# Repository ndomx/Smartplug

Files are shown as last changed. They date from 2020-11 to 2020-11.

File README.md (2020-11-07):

# Smartplug
WiFi controller for home automation

## Description
A smartplug is a device with which you can control the conection of an appliance remotely. As of version 2, I'm using an ESP8266 micro-controller, and controlling it using MQTT.

The schematics are publicly available in this repository, and the fabrication files are available in the releases page. All the required codes are also publicly available here, though you'll have to setup your Arduino IDE to program the MCU. Refer to the [libraries guide](./LIBRARIES_GUIDE.md) to learn how to do it.

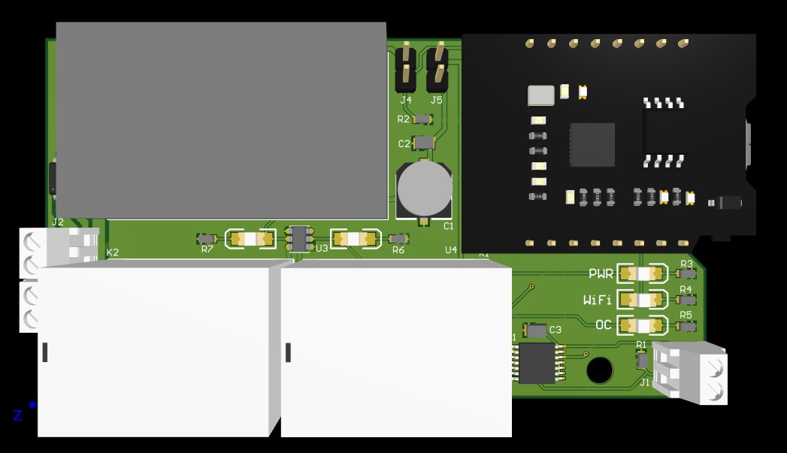
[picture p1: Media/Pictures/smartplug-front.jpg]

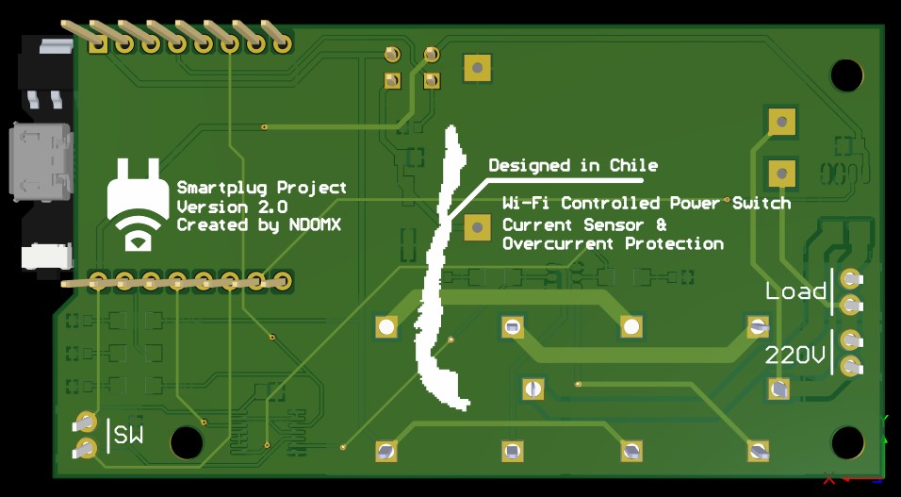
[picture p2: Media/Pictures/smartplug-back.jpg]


## Functionality
### Basics
The basic operation of the smartplug is fairly simple. It's a commutator circuit just like those lights, found commonly in stairs, that can be controlled by two switches. The circuit goes as follows:
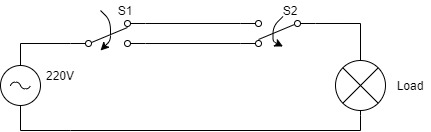
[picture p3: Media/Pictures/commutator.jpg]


Current can flow through the load (a light bulb) when bith switches are in the same state. The smartplug works the same way, but instead of having two switches, it has two relays that are controlled by the MCU.
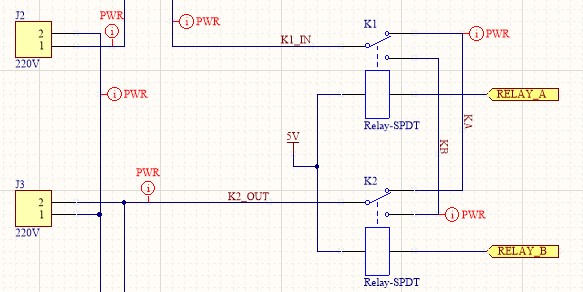
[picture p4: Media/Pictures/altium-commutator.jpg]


The MCU controls both signals, **RELAY_A** and **RELAY_B** that toggle each switch. One control signal is controlled remotely (via MQTT) while the other is controlled by an external switch.

The smartplug has two modes of operation:
1. Take absolute control of the load remotely, i.e. connect/disconnect the load remotely regardless of the external switch input
2. Use the smartplug as a traditional commutator circuit, i.e. the load will toggle every time each control signal is toggled, wether its via MQTT or physical input

> I noticed only one relay is necessary to achieve the same behaviour. So V3 will drop one relay and handle all the logic by software.

The mode of operation is controlled by the header J4.
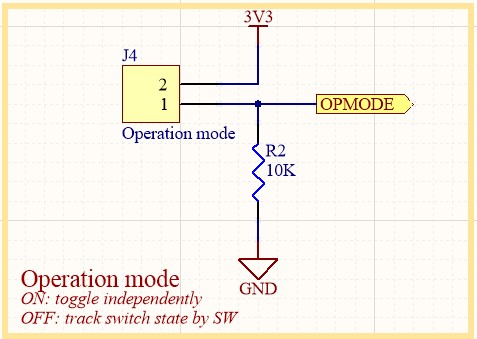
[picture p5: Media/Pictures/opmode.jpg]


### Power
The PCB traces were calculated for 5A max. In countries with 220V/50Hz supply, this can power 1kW loads. In countries with 110V/60Hz, the max output power is limited to 0.5kW.

On the other hand, all the electronics can be powered by the AC/DC module **X1**, or by external 5V connected to the USB connector, as shown in the image below.
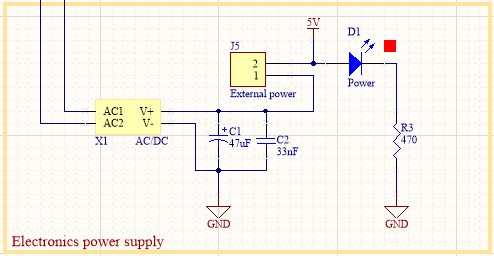
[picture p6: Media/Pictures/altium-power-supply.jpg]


Connect the jumper **J5** to enable power input from the AC/DC module, or leave disconnected and power via USB cable.
> Powering the device via USB cable is meant for uploading the firmware to the MCU. For other purposes, the use of the AC/DC module is recommended

### Current sensing
The smartplug is equipped with an ACS712 current sensor. The current is measured by the MCU ADC and uploaded to the server.

Additionally, if and overcurrent is detected, the OC flag will be activated (~OC as it is active low) and the output will be disabled.

The SN74LV (**U1**) is a quad NAND gate that implements the logic circuit that ensures the load remains unconnected while the OC flag is active.
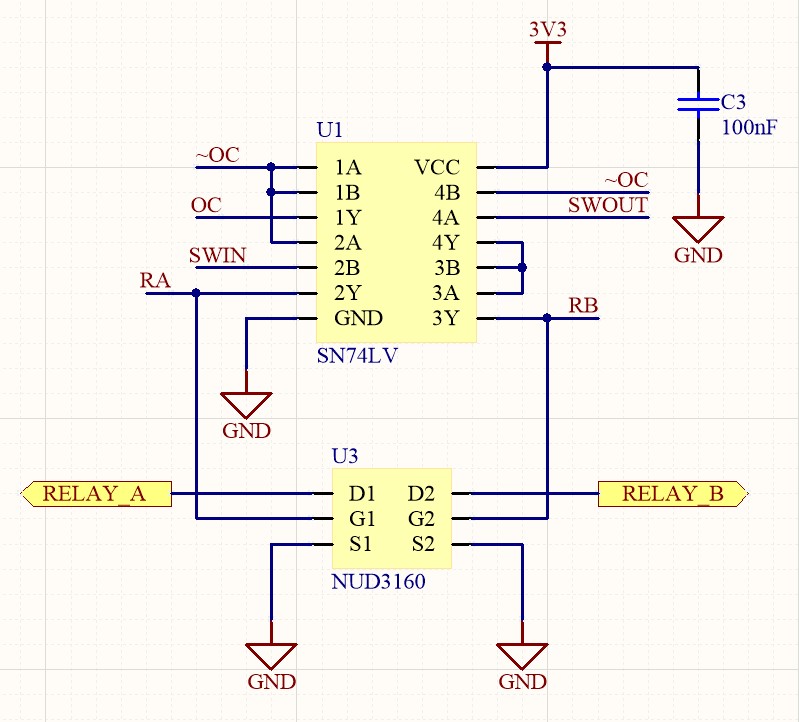
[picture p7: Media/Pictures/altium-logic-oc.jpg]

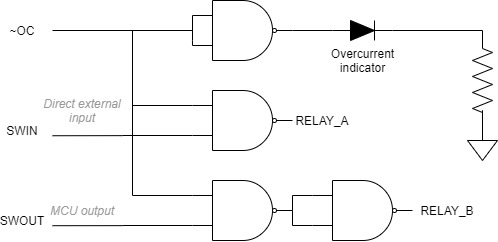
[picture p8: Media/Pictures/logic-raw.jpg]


When ~OC goes low, the outputs **RELAY_A** and **RELAY_B** will go HIGH/LOW repectively, thus, shutting down the load.

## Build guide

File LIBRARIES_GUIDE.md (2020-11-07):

# LIBRARIES GUIDE

## 1. ESP8266 Arduino library
1. Open the Arduino IDE
2. Go to _File_ > _Preferences_ and complete the field _Additional Boards Manager URLs_ with the following link ``http://arduino.esp8266.com/stable/package_esp8266com_index.json``
3. Go to _Tools_ > _Board_ > _Boards Manager..._
4. Search for ``esp8266`` and install the library **esp8266** by **ESP8266 Community**.
   
## 2. PubSubClient Arduino library
1. Open the Arduino IDE.
2. Go to _Sketch_ > _Include Library_ > _Manage Libraries..._
3. Search for ``PubSubClient`` and install the library **PubSubClient** by **Nick O'Leary**

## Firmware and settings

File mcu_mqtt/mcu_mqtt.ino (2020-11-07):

/*
 * Smartplug controller code for ESP8266.
 * Author: ndomx (https://github.com/ndomx)
 * 
 * This code uses the PubSubClient library and
 * is based on the example code provided the author.
 * Original code available on:
 * https://github.com/knolleary/pubsubclient/blob/master/examples/mqtt_esp8266/mqtt_esp8266.ino
 */

#include <Ticker.h>
#include <ESP8266WiFi.h>
#include <PubSubClient.h>

#include "private_data.h"
#include "esp8266_header.h"

String clientId = "ESP8266-sp1"; // Be sure to change it for each device

WiFiClient espClient;
PubSubClient client(espClient);

char pub_msg[PUB_MSG_LENGTH];

Ticker rms_calculation;
float amps_array[AMPS_ARRAY_LENGTH];
int amps_index;

float amps_rms;

long last_measurement;
bool is_resting;

void setup()
{
    pinMode(SWOUT, OUTPUT);
    pinMode(SWIN, INPUT);
    pinMode(OC, OUTPUT);
    pinMode(LED_WIFI, OUTPUT);
    pinMode(ADC_PIN, INPUT);

    // Ensure the OC flag starts deactivated
    digitalWrite(OC, HIGH);

    Serial.begin(115200);
    setup_wifi();
    setup_mqtt();

    rms_calculation.attach_ms(TICKER_INTERVAL_MS, measure_amps);
}

void loop()
{
    if (!client.connected())
    {
        reconnect();
    }
    client.loop();

    if (is_resting)
    {
        long now = millis();
        if (now - last_measurement > TICKER_REST_MS)
        {
            is_resting = false;
            rms_calculation.attach_ms(TICKER_INTERVAL_MS, measure_amps);
        }
    }
}

void setup_wifi()
{
    delay(10);
    
    Serial.println();
    Serial.print("Connecting to ");
    Serial.println(ssid);

    WiFi.begin(ssid, password);

    bool led_state = LOW;

    while (WiFi.status() != WL_CONNECTED)
    {
        delay(500);
        Serial.print(".");

        digitalWrite(LED_WIFI, led_state);
        led_state ^= HIGH;
    }

    Serial.println("");
    Serial.println("WiFi connected");
    Serial.println("IP address: ");
    Serial.println(WiFi.localIP());

    digitalWrite(LED_WIFI, LOW);
}

void setup_mqtt()
{
    client.setServer(mqtt_server, 1883);
    client.setCallback(on_message);

    client.subscribe(topic_power);
}

void on_message(char *topic, byte *payload, unsigned int length)
{
    digitalWrite(LED_WIFI, HIGH);

    Serial.print(topic);
    Serial.print(" | ");
    for (int i = 0; i < length; i++)
    {
        Serial.print((char)payload[i]);
    }
    Serial.println();
    
    toggle_plug(payload[0] == '1');

    digitalWrite(LED_WIFI, LOW);
}

void reconnect()
{
    digitalWrite(LED_WIFI, HIGH);
    while (!client.connected())
    {
        Serial.print("Attempting MQTT connection...");
        
        if (client.connect(clientId.c_str()))
        {
            Serial.println("connected");
            client.subscribe(topic_power);
        }
        else
        {
            Serial.print("failed, rc=");
            Serial.print(client.state());
            Serial.println(" try again in 5 seconds");
            delay(5000);
        }
    }
}

void publish(void)
{
    Serial.print("Publish: [");
    Serial.print(topic_amps);
    Serial.print("] amps_rms = ");
    Serial.println(amps_rms);
    
    snprintf(pub_msg, PUB_MSG_LENGTH, "amps_rms: %f", amps_rms);
    client.publish(topic_amps, pub_msg);
}

void measure_amps()
{
    // The current sample has an offset of Vdd/2,
    // so its necessary to substract 1024/2 from the
    // sampled value
    float amps = (analogRead(ADC_PIN) - 512) * MAX_AMPS / 512;

    amps_array[amps_index++] = amps * amps;
    if (amps_index >= AMPS_ARRAY_LENGTH)
    {
        amps_index = 0;
        on_measurement_ready();
    }
}

void on_measurement_ready()
{
    rms_calculation.detach();

    calculate_amps_rms();
    publish();

    last_measurement = millis();
    is_resting = true;
}

void calculate_amps_rms()
{
    float sum;
    for (int idx = 0; idx < AMPS_ARRAY_LENGTH; idx++)
    {
        sum += amps_array[idx];
    }
    
    amps_rms = sum / AMPS_ARRAY_LENGTH;
    /*
     * Technically, amps_rms would be equal to the sqrt of
     * the actual quantity, but its best not to calculate
     * sqrts in the mcu, but to calculate them server side
     */

    if (amps_rms > OVERCURRENT_TH * OVERCURRENT_TH)
    {
        // Theres no software way of clearing the OC flag
        // To turn it off, the MCU must be resetted
        digitalWrite(OC, LOW);
    }
}

void toggle_plug(bool next_state)
{
    bool opmode = digitalRead(OPMODE);
    if (opmode)
    {
        bool swin = digitalRead(SWIN);
        digitalWrite(SWOUT, swin);
    }
    else
    {
        digitalWrite(SWOUT, next_state);
    }
}

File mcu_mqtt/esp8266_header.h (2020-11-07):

/*
 * Header file for functions:
 * This file is read before the main code by the compiler, and so,
 * it allow us to make use of this functions before declaring them
 * in the main code.
 * 
 * The use of this kind of files is absolutely optional for small
 * codes/projects like this one, but I find it a good practice to
 * use them anyway.
 */

#ifndef ESP8266_HEADER_H
#define ESP8266_HEADER_H

#include <Arduino.h>

#define SWOUT D6
#define SWIN D0
#define OPMODE D3
#define OC D1
#define LED_WIFI D8
#define ADC_PIN A0

#define PUB_MSG_LENGTH 20

#define AMPS_ARRAY_LENGTH 40
#define TICKER_INTERVAL_MS 2

#define TICKER_REST_MS 1000

#define MAX_AMPS 30.0 // Max current supported by sensor
#define OVERCURRENT_TH 5 // OC threshold

void setup_wifi(void);

void setup_mqtt(void);
void on_message(char *topic, byte *payload, unsigned int length);
void reconnect(void);
void publish(void);

void measure_amps(void);
void calculate_amps_rms(void);
void on_measurement_ready(void);

void toggle_plug(bool next_state);

#endif // ESP8266_HEADER_H

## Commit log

2018-10-07 Update file
    Updated .gitignore to ommit Eagle PCB and editor autogenerated files
2018-10-07 Add files
    Eagle PCB design for Smartplug
    [smart-plug.brd, smart-plug.sch]
2018-10-07 Add files
    Nodejs REST API to communicate with end devices
2018-10-07 Update files
    Added LED indicators
    [smart-plug.brd, smart-plug.sch]
2018-12-20 Update files
    Improved led debugging
2018-12-20 Update files
    Added on board LEDs, updated design
    [smart-plug.brd, smart-plug.sch]
2018-12-20 Update mcu_mqtt.ino
    Changed RED LED pin
2018-12-21 Update mcu_mqtt.ino
    Set LED pins to output
2019-01-12 Update files
    Removed fuse and made PCB smaller
    [smart-plug.brd, smart-plug.sch]
2019-01-12 Add files via upload
    Gerber files for PCB fabrication
2019-01-13 Update mcu_mqtt.ino
    Added current sensor and now the smartplug supports not only to toggle on/off but to choose the state
2019-01-14 Update PCB files
    Improved design, added SMD components and current sensor
    [smart-plug.brd, smart-plug.sch]
2020-11-06 PCB Version 2
    Newly improved design in Altium
    [1x2 Male-Pin-Header.STEP, ACS722LLC.STEP, CAP_UCD_6P3X5P8-L.step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]
2020-11-07 Add altium files to repository
    [1x2 Male-Pin-Header.STEP, ACS722LLC.STEP, CAP_UCD_6P3X5P8-L.step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]
2020-11-07 Fix wiring mistake
    [Control.SchDoc, Smartplug.PcbDoc]
2020-11-10 Update to V3
    [Control.SchDoc, Interface.SchDoc, Power.SchDoc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]
2020-11-10 Make schematics update
    [Control.SchDoc, Interface.SchDoc, Power.SchDoc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]
2020-11-16 Update schematics
    [Control.SchDoc, Power.SchDoc, Smartplug.PcbDoc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]
2021-04-06 Finish v3 design
    [Control.SchDoc, Power.SchDoc, Smartplug.PcbDoc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]
